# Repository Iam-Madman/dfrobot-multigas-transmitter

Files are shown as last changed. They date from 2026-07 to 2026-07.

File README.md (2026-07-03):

# DFRobot Multi-Gas Transmitter

An industrial-grade, multi-phase gas monitoring system implementing the Modbus RTU protocol over RS-485. This repository serves as a monorepo containing everything from the initial rapid hardware prototypes to production-ready firmware and hardware fabrication files.

---

## Repository Structure

The project separates hardware development from firmware development ecosystems across distinct execution phases:

```text
.
├── fabrication/                 
└── firmware/
    ├── arduino_nano_firmware/   
    └── bluepill_firmware/

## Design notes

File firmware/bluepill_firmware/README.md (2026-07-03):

## Debugging Clone STM32F103 Chips via Black Magic Probe (BMP)

This project utilizes a **clone/non-STMicroelectronics microcontroller** (such as a CKS32F103 or CS32F103 with Designer ID `0x80e` and Part ID `0x410`) on a Bluepill form factor.

Because the Black Magic Probe (BMP) identifies this target as an unknown ARM Cortex-M device, it cannot natively parse the chip's flash size or memory layout. To debug or attach to FreeRTOS tasks successfully without GDB or the IDE extension crashing, you **must manual override the memory map and layout settings.**

---

##  Prerequisites & Hardware Setup

### 1. Black Magic Probe Initialization

Before attempting to debug, make sure your probe is correctly provisioned, updated, and that your local user has permissions to access the serial ports (`/dev/ttyBmpGdb` and `/dev/ttyBmpTarg`).

* Refer to the official documentation for first-time native setup: [Black Magic Probe Getting Started Guide](https://black-magic.org/getting-started.html)

### 2. Project Configuration via STM32CubeMX

When updating peripheral layouts, pinouts, or clock trees:

* Open the `.ioc` configuration file in **STM32CubeMX**.
* Under **System Core** -> **SYS**, ensure that **Debug** is explicitly configured to **Serial Wire** (otherwise, the MCU will disable its own SWD pins on the first boot, locking you out).
* Regenerate the code template to cleanly merge changes into your existing initialization structure.

Here is the section updated to explicitly include both the **CLI (Command Line Interface)** and **GUI (Graphical User Interface)** options for STM32CubeProgrammer:

---

### 3. Flashing & Recovering via STM32CubeProgrammer (GUI or CLI)

Because clone chips can exhibit erratic flash controller behaviors during active debug sessions, GDB may occasionally fail to erase or program the chip. Use **STM32CubeProgrammer** via an ST-LINK V2 interface as an out-of-band utility to completely wipe or force-flash the target binary.

* **Using the GUI Application:**
1. Open the **STM32CubeProgrammer** graphical interface.
2. Set the connection type to **ST-LINK** and interface to **SWD**.
3. Change the **Mode** dropdown to **Under Reset** (this pulls the physical NRST line low to bypass execution crashes or active locks).
4. Connect, use the **Full chip erase** button (trash can icon) if the chip is completely locked up, or open your built `.elf`/`.bin` file to program and run.

##  Required Manual GDB Sequence

When initializing a raw GDB session (`arm-none-eabi-gdb`), execute the following commands in order to connect, configure the memory spaces, and attach to the target:

```text
# 1. Connect to the Black Magic Probe GDB Server port
target extended-remote /dev/ttyBmpGdb

# 2. Scan the SWD interface for the target micro
monitor swdp_scan

# 3. Attach to the discovered target ID (usually 1)
attach 1

# 4. Disable GDB restriction on unmapped memory regions
set mem inaccessible-by-default off

# 5. Force-define the Flash (Read-Only) and RAM (Read-Write) boundaries for the Clone
mem 0x08000000 0x0801FFFF ro
mem 0x20000000 0x20004FFF rw

# 6. Enable hardware breakpoints automatically for Read-Only memory locations
set breakpoint auto-hw on

# 7. Enable clean, formatted structure printouts
set print pretty on

```

---

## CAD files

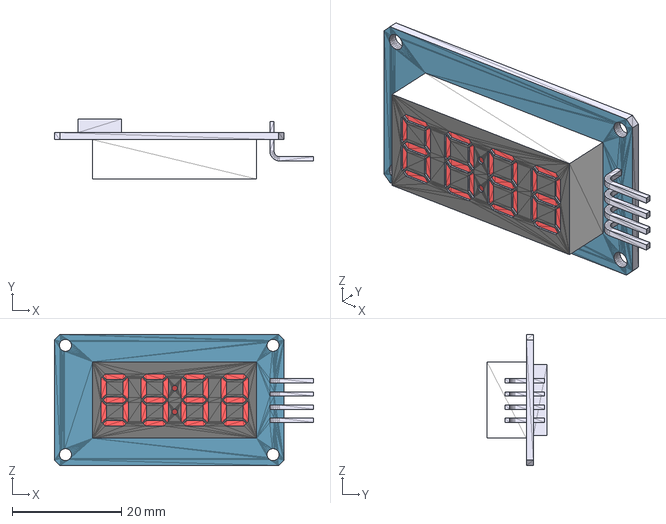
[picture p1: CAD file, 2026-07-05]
fabrication/arduino_nano_pcb(phase1)/3d_models/1Display TM1637.step
47.4 x 11.0 x 24.0 mm

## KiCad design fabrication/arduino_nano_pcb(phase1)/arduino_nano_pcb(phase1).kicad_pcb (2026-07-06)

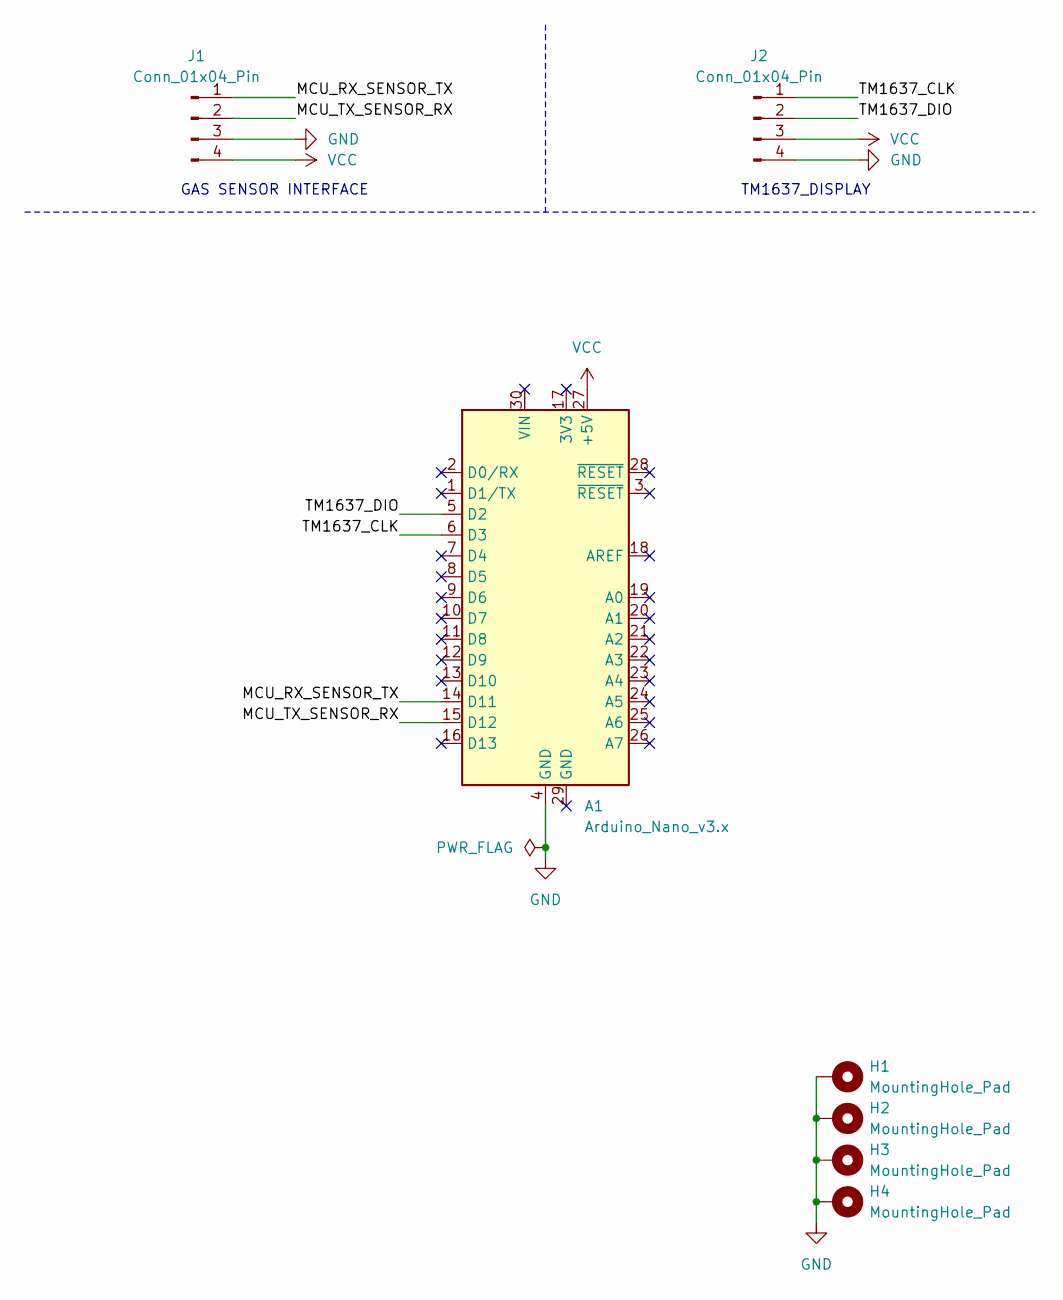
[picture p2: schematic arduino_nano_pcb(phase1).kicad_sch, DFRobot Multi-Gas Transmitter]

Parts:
A1: Arduino_Nano_v3.x; Arduino_Nano
H1, H2, H3, H4: MountingHole_Pad; MountingHole_5mm_Pad_TopBottom
J1: Conn_01x04_Pin; PinHeader_1x04_P2.54mm_Horizontal
J2: Conn_01x04_Pin; TM1637

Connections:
/MCU_RX_SENSOR_TX: A1.14 (D11), J1.1
/MCU_TX_SENSOR_RX: A1.15 (D12), J1.2
/TM1637_CLK: A1.6 (D3), J2.1
/TM1637_DIO: A1.5 (D2), J2.2
GND: A1.4 (GND), H1.1 (1_1), H2.1 (1_1), H3.1 (1_1), H4.1 (1_1), J1.3, J2.4
VCC: A1.27 (+5V), J1.4, J2.3

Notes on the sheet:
TM1637_DISPLAY
GAS SENSOR INTERFACE

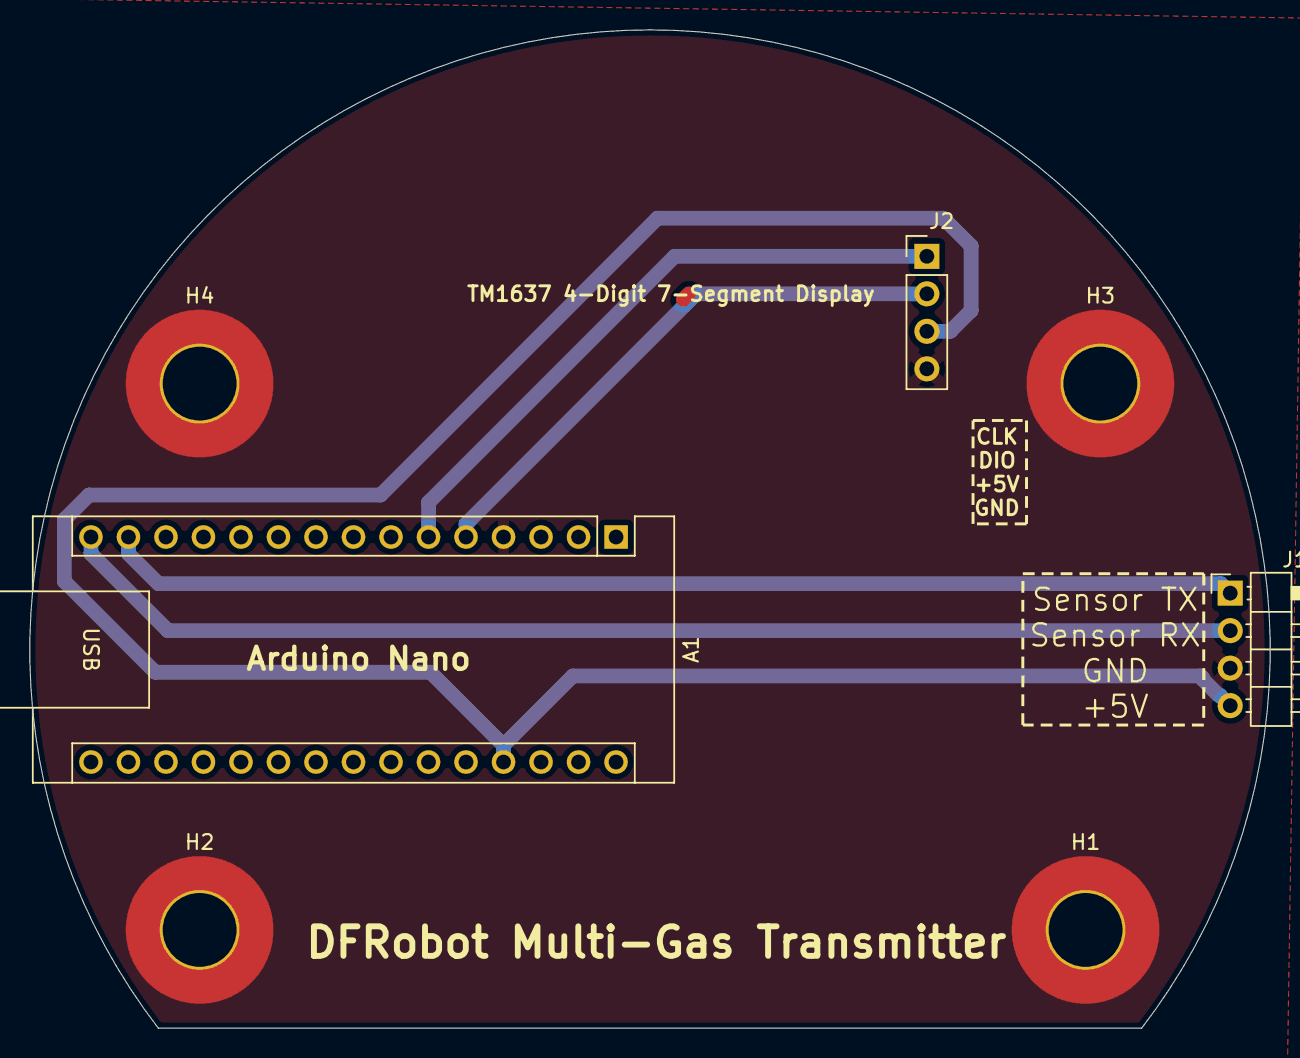
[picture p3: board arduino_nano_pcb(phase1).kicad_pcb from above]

Board: 2 copper layers, 84.0 x 67.6 mm, 7 parts (0 on the bottom side), 6 nets.

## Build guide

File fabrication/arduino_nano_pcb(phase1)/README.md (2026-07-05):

## Phase 1 Hardware Prototyping

The Phase 1 board utilizes an Arduino Nano baseboard designed for rapid validation of the TM1637 display interface and the DFRobot gas sensor lines. The traces have been widened to optimized thresholds (0.8mm–1.0mm) to allow for reliable manual mechanical isolation milling.

### Board Previews

| |
|---|
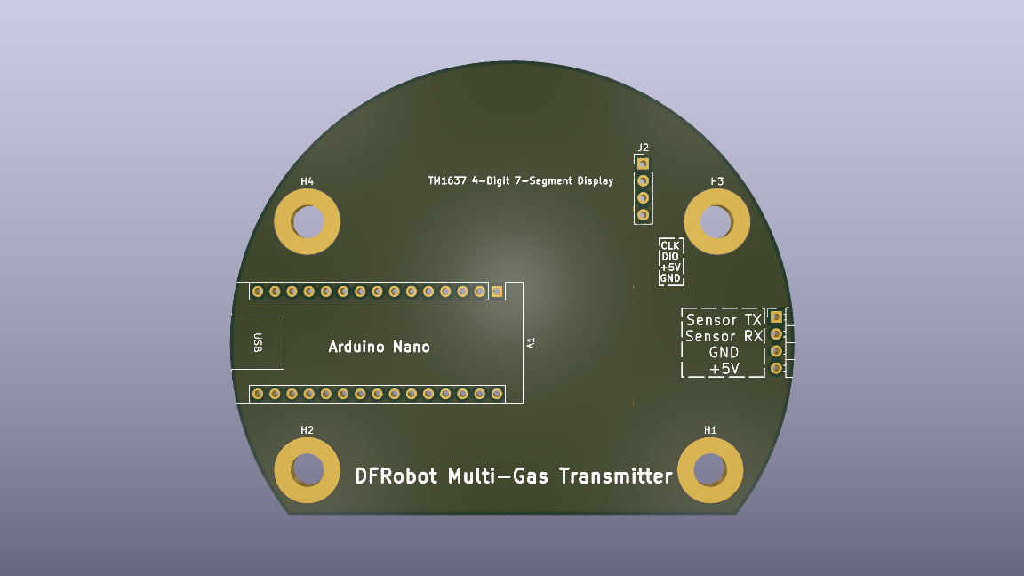
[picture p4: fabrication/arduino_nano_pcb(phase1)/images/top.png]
Top View
|  |
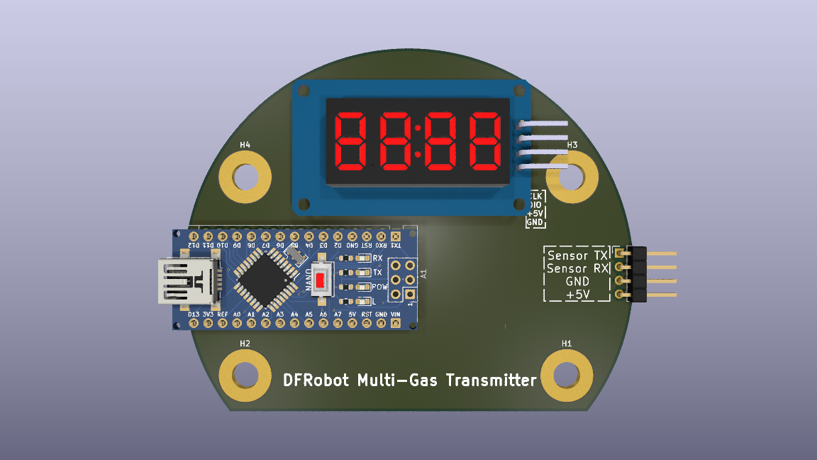
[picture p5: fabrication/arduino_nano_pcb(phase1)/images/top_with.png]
Top View with components
|  |

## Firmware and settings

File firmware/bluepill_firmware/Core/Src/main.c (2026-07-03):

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
/* Includes ------------------------------------------------------------------*/
#include "main.h"
#include "cmsis_os.h"

/* USER CODE BEGIN Includes */
#include "Modbus.h"
#include <string.h>
/* USER CODE END Includes */

/* USER CODE BEGIN PTD */
typedef struct {
    osMutexId_t Sensor_data;             // Handle for the unique mutex lock
    volatile uint16_t Sensor_value;       // Processed Sensor value
} SensorData_t;
/* USER CODE END PTD */

ADC_HandleTypeDef hadc1;
DMA_HandleTypeDef hdma_adc1;

IWDG_HandleTypeDef hiwdg;

TIM_HandleTypeDef htim2;
TIM_HandleTypeDef htim3;

UART_HandleTypeDef huart1;
DMA_HandleTypeDef hdma_usart1_rx;
DMA_HandleTypeDef hdma_usart1_tx;

/* Definitions for ADC_task */
osThreadId_t ADC_taskHandle;
const osThreadAttr_t ADC_task_attributes = {
  .name = "ADC_task",
  .stack_size = 192 * 4,
  .priority = (osPriority_t) osPriorityNormal,
};
/* Definitions for Calibration_tas */
osThreadId_t Calibration_tasHandle;
const osThreadAttr_t Calibration_tas_attributes = {
  .name = "Calibration_tas",
  .stack_size = 320 * 4,
  .priority = (osPriority_t) osPriorityLow,
};
/* Definitions for Watch_dog_task */
osThreadId_t Watch_dog_taskHandle;
const osThreadAttr_t Watch_dog_task_attributes = {
  .name = "Watch_dog_task",
  .stack_size = 128 * 4,
  .priority = (osPriority_t) osPriorityLow,
};
/* Definitions for Config_monitor_ */
osThreadId_t Config_monitor_Handle;
const osThreadAttr_t Config_monitor__attributes = {
  .name = "Config_monitor_",
  .stack_size = 128 * 4,
  .priority = (osPriority_t) osPriorityLow,
};
/* Definitions for Display_task */
osThreadId_t Display_taskHandle;
const osThreadAttr_t Display_task_attributes = {
  .name = "Display_task",
  .stack_size = 128 * 4,
  .priority = (osPriority_t) osPriorityLow,
};
/* Definitions for ADC_Queue */
osMessageQueueId_t ADC_QueueHandle;
const osMessageQueueAttr_t ADC_Queue_attributes = {
  .name = "ADC_Queue"
};
/* Definitions for Sensor_data */
osMutexId_t Sensor_dataHandle;
const osMutexAttr_t Sensor_data_attributes = {
  .name = "Sensor_data"
};
/* USER CODE BEGIN PV */
#define FLASH_MAGIC_KEY   0x5A42
#define HOLDING_REG_COUNT 4
#define INPUT_REG_COUNT   3

typedef struct {
    uint16_t magic;
    uint8_t slave_id;
    uint32_t baud_rate;
    uint32_t parity; 
    uint32_t stop_bits;
} DeviceConfig_t;

/* Ensure the linker script isolates this section to a specific page boundary */
__attribute__((section(".data_flash"), aligned(2048))) DeviceConfig_t Flash_Stored_Config;

/* Modbus Infrastructure */
modbusHandler_t ModbusH;
DeviceConfig_t live_cfg;

/* Separate structures matching clean industrial definitions */
uint16_t HoldingDATA[HOLDING_REG_COUNT]; // RW Configs: Status, Cal, Modbus Addr
uint16_t InputDATA[INPUT_REG_COUNT];     // RO Variables: PPM, RAW ADC

// Holding Register Offsets (FC03 / FC06)
#define REG_STATUS       0 // Address 40001
#define REG_CAL_CMD      1 // Address 40002
#define REG_MB_ADDR      2 // Address 40003

// Input Register Offsets (FC04)
#define REG_PPM_X10      0 // Address 30001
#define REG_ADC_RAW      1 // Address 30002


#define ADC_BLOCK_LEN  50
#define ADC_BUF_LEN    (ADC_BLOCK_LEN * 2) // 100 elements
volatile uint16_t adc_raw_buffer[ADC_BUF_LEN];
/* USER CODE END PV */

void SystemClock_Config(void);
static void MX_GPIO_Init(void);
static void MX_DMA_Init(void);
static void MX_ADC1_Init(void);
static void MX_TIM2_Init(void);
static void MX_USART1_UART_Init(void);
static void MX_IWDG_Init(void);
static void MX_TIM3_Init(void);
void Start_ADC_task(void *argument);
void Start_Calibration_task(void *argument);
void Start_Watch_dog_task(void *argument);
void Start_Config_monitor_task(void *argument);
void Start_Display_task(void *argument);

/* USER CODE BEGIN PFP */
void Read_Device_Configuration(void);
uint16_t Read_Physical_DIP_Switches(void);
void Program_Flash_Config(uint8_t id, uint32_t baud, uint32_t parity);

/* USER CODE END PFP */

/**
  * @brief  The application entry point.
  * @retval int
  */
int main(void)
{

  /* MCU Configuration--------------------------------------------------------*/

  /* Reset of all peripherals, Initializes the Flash interface and the Systick. */
  HAL_Init();

  /* Configure the system clock */
  SystemClock_Config();

  /* Initialize all configured peripherals */
  MX_GPIO_Init();
  MX_DMA_Init();
  MX_ADC1_Init();
  MX_TIM2_Init();
  MX_USART1_UART_Init();
  MX_IWDG_Init();
  MX_TIM3_Init();
  /* USER CODE BEGIN 2 */
// FIX: Read configuration matrix BEFORE re-initializing the UART peripheral frame
  Read_Device_Configuration();

  /* Re-initialize USART1 with dynamic parameters */
  huart1.Instance        = USART1;
  huart1.Init.BaudRate   = live_cfg.baud_rate;
  huart1.Init.Parity     = live_cfg.parity;
  huart1.Init.WordLength = (live_cfg.parity == UART_PARITY_NONE) ? UART_WORDLENGTH_8B : UART_WORDLENGTH_9B;
  huart1.Init.StopBits   = live_cfg.stop_bits;
  huart1.Init.Mode       = UART_MODE_TX_RX;
  huart1.Init.HwFlowCtl  = UART_HWCONTROL_NONE;
  huart1.Init.OverSampling = UART_OVERSAMPLING_16;

  if (HAL_UART_Init(&huart1) != HAL_OK)
  {
    Error_Handler();
  }

/* Bind and allocate Modbus Slave Engine with distinct spaces */
  ModbusH.uModbusType            = MB_SLAVE;
  ModbusH.port                   = &huart1; 
  ModbusH.u8id                   = live_cfg.slave_id;
  ModbusH.u16timeOut             = 1000;
  ModbusH.xTypeHW                = USART_HW_DMA; 
  
  // RS485 Toggling
  ModbusH.EN_Port                = GPIOA;
  ModbusH.EN_Pin                 = GPIO_PIN_8; 
  
  ModbusH.u16regs                = NULL; // Unused when separate areas are active
  ModbusH.u16regsize             = 0;
  
  // Link Read-Write Holding Region (Addresses starting at 0)
  ModbusH.u16holdingRegs         = HoldingDATA;
  ModbusH.u16holdingRegsStartAdd = 0;
  ModbusH.u16holdingRegsNregs    = HOLDING_REG_COUNT;
  
  // Link Read-Only Input Region (Addresses starting at 0)
  ModbusH.u16inputRegs           = InputDATA;
  ModbusH.u16inputRegsStartAdd   = 0;
  ModbusH.u16inputRegsNregs      = INPUT_REG_COUNT;
  
  ModbusInit(&ModbusH);
  ModbusStart(&ModbusH);
  /* USER CODE END 2 */

  /* Init scheduler */
  osKernelInitialize();
  /* Create the mutex(es) */
  /* creation of Sensor_data */
  Sensor_dataHandle = osMutexNew(&Sensor_data_attributes);

  /* USER CODE BEGIN RTOS_MUTEX */
  /* add mutexes, ... */
  /* USER CODE END RTOS_MUTEX */

  /* USER CODE BEGIN RTOS_SEMAPHORES */
  /* add semaphores, ... */
  /* USER CODE END RTOS_SEMAPHORES */

  /* USER CODE BEGIN RTOS_TIMERS */
  /* start timers, add new ones, ... */
  /* USER CODE END RTOS_TIMERS */

  /* Create the queue(s) */
  /* creation of ADC_Queue */
  ADC_QueueHandle = osMessageQueueNew (10, sizeof(uint16_t), &ADC_Queue_attributes);

  /* USER CODE BEGIN RTOS_QUEUES */
  /* add queues, ... */
  /* USER CODE END RTOS_QUEUES */

  /* Create the thread(s) */
  /* creation of ADC_task */
  ADC_taskHandle = osThreadNew(Start_ADC_task, NULL, &ADC_task_attributes);

  /* creation of Calibration_tas */
  Calibration_tasHandle = osThreadNew(Start_Calibration_task, NULL, &Calibration_tas_attributes);

  /* creation of Watch_dog_task */
  Watch_dog_taskHandle = osThreadNew(Start_Watch_dog_task, NULL, &Watch_dog_task_attributes);

  /* creation of Config_monitor_ */
  Config_monitor_Handle = osThreadNew(Start_Config_monitor_task, NULL, &Config_monitor__attributes);

  /* creation of Display_task */
  Display_taskHandle = osThreadNew(Start_Display_task, NULL, &Display_task_attributes);

  /* USER CODE BEGIN RTOS_THREADS */
  /* add threads, ... */
  /* USER CODE END RTOS_THREADS */

  /* USER CODE BEGIN RTOS_EVENTS */
  /* add events, ... */
  /* USER CODE END RTOS_EVENTS */

  /* Start scheduler */
  osKernelStart();

  /* We should never get here as control is now taken by the scheduler */

  /* Infinite loop */
  /* USER CODE BEGIN WHILE */
  while (1)
  {
    /* USER CODE END WHILE */

    /* USER CODE BEGIN 3 */
  }
  /* USER CODE END 3 */
}

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
/* USER CODE BEGIN 4 */
void Read_Device_Configuration(void)
{
    // Check Pin PA0 (DIP Switch 1 - Configuration Mode)
    if (HAL_GPIO_ReadPin(GPIOA, GPIO_PIN_0) == GPIO_PIN_SET) 
    {
        /* ─── SOFTWARE MODE (Read Flash) ─── */
        if (Flash_Stored_Config.magic == FLASH_MAGIC_KEY) 
        {
            live_cfg.slave_id  = Flash_Stored_Config.slave_id;
            live_cfg.baud_rate = Flash_Stored_Config.baud_rate;
            live_cfg.parity    = Flash_Stored_Config.parity;
            live_cfg.stop_bits = Flash_Stored_Config.stop_bits;
        } 
        else 
        {
            /* Fallback Safe Defaults */
            live_cfg.slave_id  = 1;
            live_cfg.baud_rate = 9600;
            live_cfg.parity    = UART_PARITY_NONE;
            live_cfg.stop_bits = UART_STOPBITS_2; 
        }
    } 
    else 
    {
        /* ─── HARDWARE MODE (Read 16-Bit Switch Matrix) ─── */
        uint16_t dip_switches = Read_Physical_DIP_Switches();
        live_cfg.slave_id = ((dip_switches >> 1) & 0xFF) + 1;

        uint8_t baud_selection = (dip_switches >> 9) & 0x07;
        switch (baud_selection) {
            case 0x01: live_cfg.baud_rate = 14400;  break;
            case 0x02: live_cfg.baud_rate = 19200;  break;
            case 0x03: live_cfg.baud_rate = 38400;  break;
            case 0x04: live_cfg.baud_rate = 57600;  break;
            case 0x05: live_cfg.baud_rate = 115200; break;
            default:   live_cfg.baud_rate = 9600;   break;
        }

        uint8_t parity_selection = (dip_switches >> 12) & 0x03;
        if (parity_selection == 0x01) {
            live_cfg.parity = UART_PARITY_EVEN;
            live_cfg.stop_bits = UART_STOPBITS_1;
        } else if (parity_selection == 0x02) {
            live_cfg.parity = UART_PARITY_ODD;
            live_cfg.stop_bits = UART_STOPBITS_1;
        } else {
            live_cfg.parity = UART_PARITY_NONE;
            live_cfg.stop_bits = (HAL_GPIO_ReadPin(GPIOB, GPIO_PIN_1) == GPIO_PIN_RESET) ? 
                                 UART_STOPBITS_1 : UART_STOPBITS_2;
        }
    }
}

uint16_t Read_Physical_DIP_Switches(void)
{
    // Realize your shift registers or GPIO read configurations here.
    // Returning a dummy layout matching your mask definitions for testing:
    return 0x0000; 
}

void Program_Flash_Config(uint8_t id, uint32_t baud, uint32_t parity)
{
    DeviceConfig_t working_packet;
    working_packet.magic     = FLASH_MAGIC_KEY;
    working_packet.slave_id  = id;
    working_packet.baud_rate = baud;
    working_packet.parity    = parity;
    
    if (parity == UART_PARITY_NONE) {
        working_packet.stop_bits = (live_cfg.stop_bits == UART_STOPBITS_1) ? UART_STOPBITS_1 : UART_STOPBITS_2;
    } else {
        working_packet.stop_bits = UART_STOPBITS_1;
    }

    // 1. Stop active UART DMA communication pipelines before tearing down peripherals
    HAL_UART_DMAStop(&huart1);
    
    // 2. Lock Modbus semaphore to safely modify shared registers and hardware frames
    if (osSemaphoreAcquire(ModbusH.ModBusSphrHandle, osWaitForever) == osOK) 
    {
        /* Update runtime configuration context */
        live_cfg.slave_id  = working_packet.slave_id;
        live_cfg.baud_rate = working_packet.baud_rate;
        live_cfg.parity    = working_packet.parity;
        live_cfg.stop_bits = working_packet.stop_bits;

        /* Re‑initialize the UART peripheral with new dynamic parameters */
        huart1.Init.BaudRate   = live_cfg.baud_rate;
        huart1.Init.Parity     = live_cfg.parity;
        huart1.Init.WordLength = (live_cfg.parity == UART_PARITY_NONE) ? UART_WORDLENGTH_8B : UART_WORDLENGTH_9B;
        huart1.Init.StopBits   = live_cfg.stop_bits;
        
        if (HAL_UART_Init(&huart1) != HAL_OK) 
        {
            Error_Handler();
        }

        /* Restart DMA receive engine with idle‑line detection (as used by ModbusStart) */
        // MAX_BUFFER matches the library's buffer boundary configuration
        if (HAL_UARTEx_ReceiveToIdle_DMA(&huart1, ModbusH.xBufferRX.uxBuffer, MAX_BUFFER) != HAL_OK) 
        {
            Error_Handler();
        }
        __HAL_DMA_DISABLE_IT(huart1.hdmarx, DMA_IT_HT); // Disable half‑transfer interrupt to prevent unexpected splits

        /* Update Modbus engine identification properties */
        ModbusH.u8id = live_cfg.slave_id;

        /* Reset the ring buffer state and internal metrics counters */
        RingClear(&ModbusH.xBufferRX);
        ModbusH.u8lastRec    = 0;
        ModbusH.u8BufferSize = 0;
        ModbusH.u16InCnt     = 0;
        ModbusH.u16OutCnt    = 0;
        ModbusH.u16errCnt    = 0;

        // Release semaphore resource
        osSemaphoreRelease(ModbusH.ModBusSphrHandle);
    }

    // 3. Write the new configuration structure into Non-Volatile Flash memory
    // CRITICAL: Do NOT disable global interrupts here or use osKernelLock(). 
    // Flash programming takes up to 40ms; halting interrupts triggers an IWDG Watchdog reset.
    HAL_FLASH_Unlock();
    __HAL_FLASH_CLEAR_FLAG(FLASH_FLAG_EOP | FLASH_FLAG_PGERR | FLASH_FLAG_WRPERR);

    FLASH_EraseInitTypeDef erase_init;
    erase_init.TypeErase   = FLASH_TYPEERASE_PAGES;
    erase_init.PageAddress = (uint32_t)&Flash_Stored_Config;
    erase_init.NbPages     = 1;

    uint32_t page_error = 0;
    if (HAL_FLASHEx_Erase(&erase_init, &page_error) == HAL_OK) 
    {
        uint32_t *source_ptr  = (uint32_t*)&working_packet;
        uint32_t *dest_ptr    = (uint32_t*)&Flash_Stored_Config;
        size_t words_to_write = sizeof(DeviceConfig_t) / 4;
        
        for (size_t i = 0; i < words_to_write; i++) 
        {
            HAL_FLASH_Program(FLASH_TYPEPROGRAM_WORD, (uint32_t)(dest_ptr + i), *(source_ptr + i));
        }
    }
    HAL_FLASH_Lock();
}
void HAL_ADC_ConvHalfCpltCallback(ADC_HandleTypeDef* hadc)
{
  if(hadc->Instance == ADC1)
  {
    osThreadFlagsSet(ADC_taskHandle, 0x01); 
  }
}

void HAL_ADC_ConvCpltCallback(ADC_HandleTypeDef* hadc)
{
  if(hadc->Instance == ADC1)
  {
    osThreadFlagsSet(ADC_taskHandle, 0x02); 
  }
}

/* USER CODE END 4 */

/* USER CODE BEGIN Header_Start_ADC_task */
/**
  * @brief  Function implementing the ADC_task thread.
  * @param  argument: Not used
  * @retval None
  */
/* USER CODE END Header_Start_ADC_task */
void Start_ADC_task(void *argument)
{
  /* USER CODE BEGIN 5 */
  
  // Start continuous ADC acquisition via hardware timer triggers
  HAL_ADC_Start_DMA(&hadc1, (uint32_t *)(uintptr_t)adc_raw_buffer, ADC_BUF_LEN);
  HAL_TIM_Base_Start(&htim3);
  uint32_t flags;
  /* Infinite loop */
  for(;;)
  {
  flags = osThreadFlagsWait(0x01 | 0x02, osFlagsWaitAny, osWaitForever);

	  // 2. Determine which offset to read based on the flag set in the ISR
	  uint32_t buffer_offset = 0;
  if (flags & 0x02)
    {
      buffer_offset = ADC_BLOCK_LEN; // Point to index 64 (Second Half)
    }
    else if (flags & 0x01)
    {
      buffer_offset = 0;              // Point to index 0 (First Half)
    }

	  // 3. Compute the average safely from the stable half
	  uint32_t sum = 0;
	  for(int i = 0; i < ADC_BLOCK_LEN; i++)
	  {
		sum += adc_raw_buffer[buffer_offset + i];
	  }
	  
	  uint16_t ADC_average = sum / ADC_BLOCK_LEN;

  osStatus_t queue_status = osMessageQueuePut(ADC_QueueHandle, &ADC_average, 0, 0);
    if (queue_status != osOK)
    {
        /* FIX: Protect shared register from Modbus data races */
        if (osMutexAcquire(Sensor_dataHandle, osWaitForever) == osOK)
        {
            HoldingDATA[REG_STATUS] |= (1 << 4); // Set overflow flag safely
            osMutexRelease(Sensor_dataHandle);
        }
    }
    }
  /* USER CODE END 5 */
}

/* USER CODE BEGIN Header_Start_Calibration_task */
/**
* @brief Function implementing the Calibration_tas thread.
* @param argument: Not used
* @retval None
*/
/* USER CODE END Header_Start_Calibration_task */
void Start_Calibration_task(void *argument)
{
  /* USER CODE BEGIN Start_Calibration_task */
  uint16_t received_ADC_average;
  osStatus_t queue_status;
  /* Infinite loop */
for (;;)
{
  queue_status = osMessageQueueGet(ADC_QueueHandle, & received_ADC_average, NULL, osWaitForever);
  if (queue_status == osOK)
  {
    float ppm = (float) received_ADC_average * 0.75f;
    // FIX: Secure the actual binary semaphore used by the background Modbus engine thread
    if (osSemaphoreAcquire(ModbusH.ModBusSphrHandle, osWaitForever) == osOK)
    {
      InputDATA[REG_ADC_RAW] = received_ADC_average;
      InputDATA[REG_PPM_X10] = (uint16_t)(ppm * 10.0f);
      HoldingDATA[REG_STATUS] = 0x01;
      osSemaphoreRelease(ModbusH.ModBusSphrHandle);
    }
   }
  }
  /* USER CODE END Start_Calibration_task */
}

/* USER CODE BEGIN Header_Start_Watch_dog_task */
/**
* @brief Function implementing the Watch_dog_task thread.
* @param argument: Not used
* @retval None
*/
/* USER CODE END Header_Start_Watch_dog_task */
void Start_Watch_dog_task(void *argument)
{
  /* USER CODE BEGIN Start_Watch_dog_task */
  /* Infinite loop */
  for(;;)
  {
    osDelay(1000);                 // wait 1 second
    HAL_IWDG_Refresh(&hiwdg);      // reset the watchdog counter
  }
  /* USER CODE END Start_Watch_dog_task */
}

/* USER CODE BEGIN Header_Start_Config_monitor_task */
/**
* @brief Function implementing the Config_monitor_ thread.
* @param argument: Not used
* @retval None
*/
/* USER CODE END Header_Start_Config_monitor_task */
void Start_Config_monitor_task(void *argument)
{
  /* USER CODE BEGIN Start_Config_monitor_task */
  /* Infinite loop */
  for(;;)
  {
    osDelay(1);
  }
  /* USER CODE END Start_Config_monitor_task */
}

/* USER CODE BEGIN Header_Start_Display_task */
/**
* @brief Function implementing the Display_task thread.
* @param argument: Not used
* @retval None
*/
/* USER CODE END Header_Start_Display_task */
void Start_Display_task(void *argument)
{
  /* USER CODE BEGIN Start_Display_task */
  /* Infinite loop */
  for(;;)
  {
    osDelay(1);
  }
  /* USER CODE END Start_Display_task */
}

/**
  * @brief  Period elapsed callback in non blocking mode
  * @note   This function is called  when TIM1 interrupt took place, inside
  * HAL_TIM_IRQHandler(). It makes a direct call to HAL_IncTick() to increment
  * a global variable "uwTick" used as application time base.
  * @param  htim : TIM handle
  * @retval None
  */
void HAL_TIM_PeriodElapsedCallback(TIM_HandleTypeDef *htim)
{
  if (htim->Instance == TIM1)
  {
    HAL_IncTick();
  }
}

/**
  * @brief  This function is executed in case of error occurrence.
  * @retval None
  */
void Error_Handler(void)
{
  /* USER CODE BEGIN Error_Handler_Debug */
  /* User can add his own implementation to report the HAL error return state */
  __disable_irq();
  while (1)
  {
  }
  /* USER CODE END Error_Handler_Debug */
}
#ifdef USE_FULL_ASSERT
/**
  * @brief  Reports the name of the source file and the source line number
  *         where the assert_param error has occurred.
  * @param  file: pointer to the source file name
  * @param  line: assert_param error line source number
  * @retval None
  */
void assert_failed(uint8_t *file, uint32_t line)
{
  /* USER CODE BEGIN 6 */
  /* User can add his own implementation to report the file name and line number,
	 ex: printf("Wrong parameters value: file %s on line %d\r\n", file, line) */
  /* USER CODE END 6 */
}
#endif /* USE_FULL_ASSERT */

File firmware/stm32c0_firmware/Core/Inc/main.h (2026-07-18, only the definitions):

#define RS485_DE_Pin LL_GPIO_PIN_1
#define RS485_DE_GPIO_Port GPIOA
#define TM1637_SCL_Pin LL_GPIO_PIN_4
#define TM1637_SCL_GPIO_Port GPIOA
#define TM1637_SDA_Pin LL_GPIO_PIN_5
#define TM1637_SDA_GPIO_Port GPIOA
#define NVIC_PRIORITYGROUP_0         ((uint32_t)0x00000007) /*!< 0 bit  for pre-emption priority,
#define NVIC_PRIORITYGROUP_1         ((uint32_t)0x00000006) /*!< 1 bit  for pre-emption priority,
#define NVIC_PRIORITYGROUP_2         ((uint32_t)0x00000005) /*!< 2 bits for pre-emption priority,
#define NVIC_PRIORITYGROUP_3         ((uint32_t)0x00000004) /*!< 3 bits for pre-emption priority,
#define NVIC_PRIORITYGROUP_4         ((uint32_t)0x00000003) /*!< 4 bits for pre-emption priority,

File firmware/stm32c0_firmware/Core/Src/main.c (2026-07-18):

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
/* Includes ------------------------------------------------------------------*/
#include "main.h"

/* USER CODE BEGIN Includes */
#include <math.h>
/* USER CODE END Includes */


/* USER CODE BEGIN PV */
// --- Global SysTick Counter Reference ---
extern __IO uint32_t uwTick; 

// --- Gas Sensor (USART1) Definitions ---
#define GAS_RX_BUF_SIZE  32
uint8_t gas_rx_buffer[GAS_RX_BUF_SIZE];
volatile uint8_t gas_rx_index = 0;
volatile uint8_t gas_data_ready = 0;
uint16_t current_gas_value = 0;

// --- Modbus RTU Slave (USART2) Definitions ---
#define MODBUS_BUF_SIZE  128
uint8_t modbus_rx_buffer[MODBUS_BUF_SIZE];
volatile uint16_t modbus_rx_index = 0;
volatile uint32_t modbus_last_rx_tick = 0;
volatile uint8_t modbus_frame_complete = 0;

// --- TM1637 State Machine Definitions ---
typedef enum {
  TM_IDLE,
  TM_START,
  TM_SEND_BYTE,
  TM_ACK,
  TM_STOP
} TM1637_State_t;

TM1637_State_t tm_state = TM_IDLE;
uint8_t tm_bit_index = 0;
volatile uint8_t display_update_required = 0;

// The complete transmission chain sequence array buffer
uint8_t tm_tx_pipeline[8]; 
uint8_t tm_pipeline_index = 0;
uint8_t tm_tx_byte = 0;

const uint8_t TM_FONT_NUM[] = {0x3F, 0x06, 0x5B, 0x4F, 0x66, 0x6D, 0x7D, 0x07, 0x7F, 0x6F};
const uint8_t TM_SEG_HEAT[] = {0x76, 0x79, 0x77, 0x38}; // H, E, A, t
const uint8_t TM_SEG_ERR[]  = {0x79, 0x50, 0x50, 0x00}; // E, r, r, [Blank]
const uint8_t TM_SEG_GOOD[] = {0x3D, 0x5C, 0x5C, 0x5E}; // G, o, o, d

// Ring buffer containing the sequenced target states to write
uint8_t tm_display_buffer[4] = {0};
/* USER CODE END PV */

void SystemClock_Config(void);
static void MX_GPIO_Init(void);
static void MX_USART1_UART_Init(void);
static void MX_USART2_UART_Init(void);

/* USER CODE BEGIN PFP */
void GasSensor_SendInit(void);
void Process_Gas_Data(void);
void Modbus_Process_State_Machine(void);
uint8_t Modbus_Validate_And_Parse(uint8_t *buffer, uint16_t length);
void TM1637_SetSegments(const uint8_t *segments);
void TM1637_ShowNumber(uint16_t value);
void TM1637_Tick_State_Machine(void);
/* USER CODE END PFP */

/**
  * @brief  The application entry point.
  * @retval int
  */
int main(void)
{

  /* MCU Configuration--------------------------------------------------------*/

  /* Reset of all peripherals, Initializes the Flash interface and the Systick. */
  LL_APB2_GRP1_EnableClock(LL_APB2_GRP1_PERIPH_SYSCFG);
  LL_APB1_GRP1_EnableClock(LL_APB1_GRP1_PERIPH_PWR);

  /* SysTick_IRQn interrupt configuration */
  NVIC_SetPriority(SysTick_IRQn, 3);

  /* Configure the system clock */
  SystemClock_Config();

  /* Initialize all configured peripherals */
  MX_GPIO_Init();
  MX_USART1_UART_Init();
  MX_USART2_UART_Init();
  /* USER CODE BEGIN 2 */
  // 1. Enable RX-Not-Empty Interrupt for both UARTs
  LL_USART_EnableIT_RXNE(USART1);
  LL_USART_EnableIT_RXNE(USART2);
  
  // 2. Ensure RS485 MAX485 is set to Receiver Mode (DE pin LOW)
  LL_GPIO_ResetOutputPin(RS485_DE_GPIO_Port, RS485_DE_Pin);

  // 3. Make sure TM1637 Open-Drain bus starts passive (HIGH via pull-ups)
  LL_GPIO_SetOutputPin(TM1637_SCL_GPIO_Port, TM1637_SCL_Pin);
  LL_GPIO_SetOutputPin(TM1637_SDA_GPIO_Port, TM1637_SDA_Pin);

  // 4. Fire the initialization packet to the Gas Sensor
  GasSensor_SendInit();
  /* USER CODE END 2 */

  /* Infinite loop */
  /* USER CODE BEGIN WHILE */
  while (1)
  {
    /* USER CODE END WHILE */

    /* USER CODE BEGIN 3 */
    static uint32_t startup_timestamp = 0;
    static uint8_t boot_phase = 0;
    
    if (startup_timestamp == 0) startup_timestamp = uwTick;

    // Non-blocking Startup Sequence Manager
    switch (boot_phase) {
      case 0: // Display "HEAt" for the first 3 seconds
        TM1637_SetSegments(TM_SEG_HEAT);
        if (uwTick - startup_timestamp >= 3000) {
          boot_phase = 1;
          startup_timestamp = uwTick;
        }
        break;

      case 1: // Run spinning animation for 3 seconds
        {
          uint32_t elapsed_anim = uwTick - startup_timestamp;
          uint8_t frame = (elapsed_anim / 250) % 4; // Advance frame every 250ms
          
          uint8_t anim_buffer[4] = {0};
          if (frame == 0)      { anim_buffer[0] = 0x01; anim_buffer[1] = 0x01; anim_buffer[2] = 0x01; anim_buffer[3] = 0x01; }
          else if (frame == 1) { anim_buffer[3] = 0x06; }
          else if (frame == 2) { anim_buffer[0] = 0x08; anim_buffer[1] = 0x08; anim_buffer[2] = 0x08; anim_buffer[3] = 0x08; }
          else                 { anim_buffer[0] = 0x30; }
          
          TM1637_SetSegments(anim_buffer);
          
          if (elapsed_anim >= 3000) {
            boot_phase = 2;
            startup_timestamp = uwTick;
          }
        }
        break;

      case 2: // Display static "Good" for 3 seconds
        TM1637_SetSegments(TM_SEG_GOOD);
        if (uwTick - startup_timestamp >= 3000) {
          boot_phase = 3; // Warm-up complete
        }
        break;

      case 3: // Operational State
        if (gas_data_ready) {
          Process_Gas_Data();
          gas_data_ready = 0;
          TM1637_ShowNumber(current_gas_value);
        }
        break;
    }

    // Process tasks concurrently 
    Modbus_Process_State_Machine();
    TM1637_Tick_State_Machine();
  }
  /* USER CODE END 3 */
}

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
/* USER CODE BEGIN 4 */
// --- GAS SENSOR IMPLEMENTATION ---
void GasSensor_SendInit(void) {
  uint8_t init_cmd[9] = {0xFF, 0x01, 0x78, 0x03, 0x00, 0x00, 0x00, 0x00, 0x84};
  
  for (uint8_t i = 0; i < 9; i++) {
    while (!LL_USART_IsActiveFlag_TXE(USART1));
    LL_USART_TransmitData8(USART1, init_cmd[i]);
  }
}

void Process_Gas_Data(void) {
  gas_rx_index = 0; 

  if (gas_rx_buffer[0] != 0xFF || gas_rx_buffer[1] != 0x88) return;

  uint8_t checksum = 0;
  for (uint8_t i = 1; i < 8; i++) {
    checksum += gas_rx_buffer[i];
  }
  checksum = (~checksum) + 1;
  if (checksum != gas_rx_buffer[8]) return; 

  uint16_t raw_concentration = (gas_rx_buffer[2] << 8) | gas_rx_buffer[3];
  uint8_t decimal_places = gas_rx_buffer[5];
  
  float resolution = 1.0f;
  if (decimal_places == 1) resolution = 0.1f;
  else if (decimal_places == 2) resolution = 0.01f;

  float final_concentration = (float)raw_concentration * resolution;
  current_gas_value = (uint16_t)(final_concentration + 0.5f); 

  uint16_t temp_adc = (gas_rx_buffer[6] << 8) | gas_rx_buffer[7];
  float vpd3 = 3.0f * (float)temp_adc / 1024.0f;
  if (vpd3 < 3.0f) {
    float rth = vpd3 * 10000.0f / (3.0f - vpd3);
    float log_rth = logf(rth / 10000.0f);
    float temp_c = 1.0f / (1.0f / (273.15f + 25.0f) + (1.0f / 3380.13f) * log_rth) - 273.15f;
    (void)temp_c; 
  }
}

// --- MODBUS RTU SLAVE IMPLEMENTATION ---
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

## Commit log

2026-06-18 feat(fixed_adc_dma): adc dma has been fixed to include a double buffer
    [main.c]
2026-07-03 feat(arduino_nano_firmware): added arduino nano firmware for the first prototyping phase
2026-07-03 feat(added_pcb_files): added fabrication files to the project
    [arduino_nano_pcb(phase1).kicad_pcb, arduino_nano_pcb(phase1).kicad_sch]
2026-07-05 feat(added_pcb_phase_1): added pcb files for the phase 1 of the project that uses arduino nano
    [arduino_nano_pcb(phase1).kicad_pcb, arduino_nano_pcb(phase1).kicad_sch]
2026-07-05 feat(added_3d_models): added new 3d models to the pcb and also added the images with those to the readme
    [arduino_nano_pcb(phase1).kicad_pcb]
2026-07-05 feat(added_gerber): added gerber files for pcb mass production
    [arduino_nano_pcb(phase1)-B_Cu.gbr, arduino_nano_pcb(phase1)-B_Mask.gbr, arduino_nano_pcb(phase1)-B_Paste.gbr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]
2026-07-05 fix(changed_model_type): changed the tm1637 model type to step , also added board step and stl files in 3d_models dir
    [1Display TM1637.step, arduino_nano_pcb(phase1).kicad_pcb]
2026-07-05 feat(pcb_rev2): modified the pcb (rev 2)
    [arduino_nano_pcb(phase1)-B_Cu.gbr, arduino_nano_pcb(phase1)-B_Mask.gbr, arduino_nano_pcb(phase1)-B_Paste.gbr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]
2026-07-06 fix(minor_footprint_fixes): minor fixes to tm1637 footprint
    [arduino_nano_pcb(phase1)-B_Cu.gbr, arduino_nano_pcb(phase1)-B_Mask.gbr, arduino_nano_pcb(phase1)-B_Paste.gbr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]
2026-07-18 feat(stm32c0_phase2): added basic pcb and firmware files for stm32c0(phase2)
    [stm32c0_pcb(phase2).kicad_pcb, stm32c0_pcb(phase2).kicad_sch]

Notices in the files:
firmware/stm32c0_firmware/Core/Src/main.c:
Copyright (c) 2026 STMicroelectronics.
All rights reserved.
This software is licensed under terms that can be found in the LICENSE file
